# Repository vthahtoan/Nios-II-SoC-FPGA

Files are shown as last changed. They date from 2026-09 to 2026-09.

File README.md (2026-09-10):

# Direct Digital Synthesizer (DDS) System on Nios II SoC

## Overview
This project presents a hardware-software co-design of a Direct Digital Synthesizer (DDS) implemented on an Altera Cyclone II FPGA (EP2C35F672C6). The system generates continuous analog waveforms, including Square, Triangle, Sine, and Cosine, by leveraging a custom digital logic circuit integrated with a Nios II embedded processor. 

## Key Features
*   **Flexible IP Core Design:** The Custom IP supports two methods for Phase-to-Amplitude conversion:
    *   **LUT (Look-Up Table):** Utilizes Block RAM for fast, 1-2 clock cycle latency.
    *   **CORDIC Algorithm:** An 8-stage pipeline architecture that computes trigonometric functions using only adders and shifters, consuming 0 bits of RAM.
*   **Avalon-MM Interface:** Seamless communication between the Nios II master and the custom DDS IP slave through the Avalon Switch Fabric.
*   **High Performance:** Achieved a maximum operating frequency (Fmax) of 208.68 MHz (CORDIC) and 195.85 MHz (LUT).
*   **Bare-metal C Software:** The Nios II processor dynamically controls the output frequency (phase increment) and wave type via low-level register manipulation.

## Repository Structure
<!-- HUONG DAN: Ban co the sua ten cac thu muc duoi day cho khop voi cay thu muc thuc te -->
    ├── doc/                 # Presentation slides, block diagrams, and waveform images
    ├── rtl/                 # Verilog HDL source files and Qsys system design
    ├── tb/                  # Testbench files for ModelSim verification
    ├── sw/                  # Embedded C code (Eclipse SBT) and BSP settings
    └── README.md

## System Architecture
The SoC architecture consists of a Nios II Processor, On-chip Memory, JTAG UART, and the custom wave_gen_avalon IP, all interconnected via the Avalon bus.

## Implementation Results & Comparison
The design was highly optimized for both logic utilization and speed. Compared to reference papers, this implementation achieves superior performance:

| Parameter | LUT Design | CORDIC Design |
| :--- | :--- | :--- |
| **Max Frequency (Fmax)** | 195.85 MHz | 208.68 MHz |
| **Block RAM usage** | ~ 0.111 BRAM | ~ 0.003 BRAM |
| **Total Equivalent Area** | 1582.5 | 2275.496 |

## Verification
The system functionality was strictly verified using:
1.  **ModelSim:** RTL waveform simulation for all wave types.
2.  **SignalTap II Logic Analyzer:** Real-time on-chip debugging to capture physical signals on the DE2 board.

## Author
*   **Võ Thanh Toàn** - *Computer Engineering, UIT*

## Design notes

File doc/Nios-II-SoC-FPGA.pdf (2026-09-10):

KHOA KỸ THUẬT MÁY TÍNH

## Nội dung trình bày:

11 May 2026 | 1

### 1. Tổng quan hệ thống phát sóng số (DDS)

### 2. Thiết kế lõi IP phần cứng

### 3. Kiến trúc SoC & Giao tiếp Avalon-MM

### 4. Tích hợp phần mềm trên Nios II

### 5. So sánh với các bài báo

### 6. Mô phỏng và Nạp KIT DE2

Copyrights 2026 UIT. All Rights Reserved.

### 1. Tổng quan về hệ thống phát sóng số (DDS)

2

DDS (Direct Digital Synthesizer): Là kỹ thuật tạo ra các dạng sóng tương tự (Sin, Cos, Tam giác, Vuông) từ một hệ thống mạch kỹ thuật số.

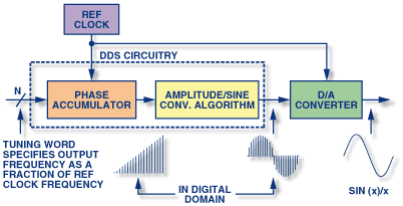
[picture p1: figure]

11 May 2026 | Copyrights 2026 UIT. All Rights Reserved.

### 1. Tổng quan về hệ thống phát sóng số (DDS)

3

Bộ cộng dồn pha (Phase Accumulator):

- Chức năng: Tích lũy giá trị bước nhảy pha sau mỗi chu kỳ clock.
- Quyết định: Tần số của tín hiệu ngõ ra.
11 May 2026 | Copyrights 2026 UIT. All Rights Reserved.

Bộ chuyển đổi Pha sang Biên độ (Phase-to-Amplitude Converter):

- Chức năng: Ánh xạ giá trị pha từ bộ cộng dồn thành biên độ sóng tương ứng.
- Phương pháp thực hiện: Bảng tra bộ nhớ (LUT) hoặc Thuật toán CORDIC.

### 1. Tổng quan về hệ thống phát sóng số (DDS)

4

Công thức tính tần số từ bước nhảy pha:

11 May 2026 | Copyrights 2026 UIT. All Rights Reserved.
- fout: Tần số của tín hiệu sóng ngõ ra mà hệ thống cần tổng hợp.
- M: Bước nhảy pha (Phase Increment)
- fclk: Tần số xung nhịp hoạt động của toàn hệ thống.
- 2

N: Độ phân giải pha tối đa, đại diện cho tổng số điểm pha rời rạc trong một chu kỳ sóng hoàn chỉnh.

### 2. Thiết kế lõi IP phần cứng

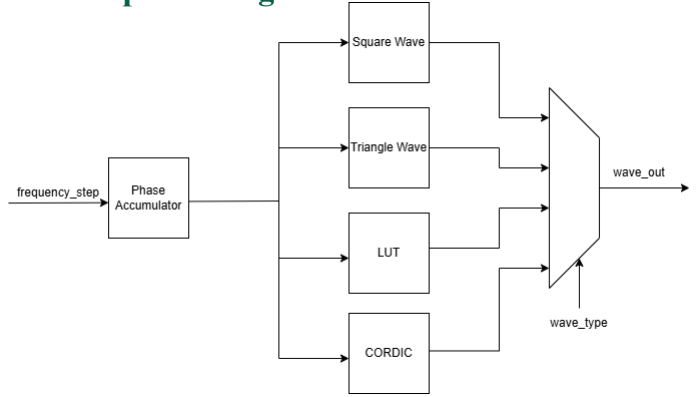
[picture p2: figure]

11 May 2026 | Copyrights 2026 UIT. All Rights Reserved. | 5

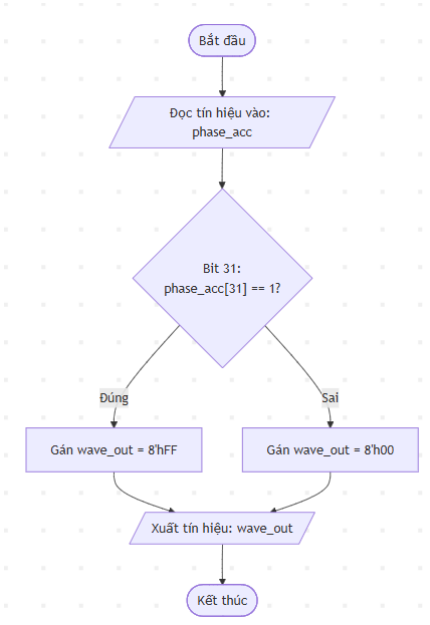
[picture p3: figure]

### 2. Thiết kế lõi IP phần cứng

### 2.1. IP tạo sóng vuông

Nguyên lý hoạt động:
- Lấy giá trị bit cao bộ cộng pha.
- Thực hiện gán giá trị cho ngõ ra phụ thuộc vào giá trị bit cao ngõ vào.

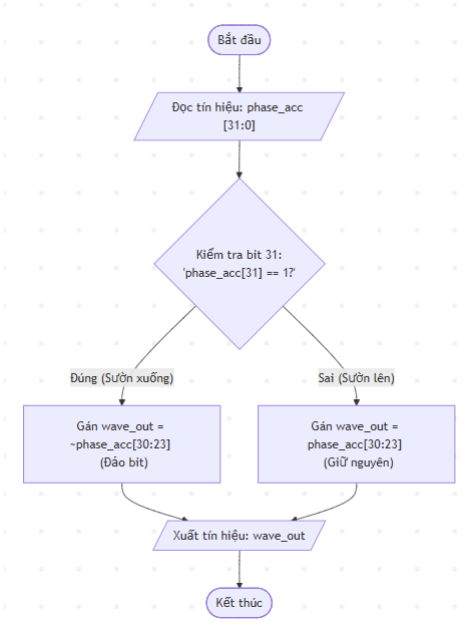
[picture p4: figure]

### 2. Thiết kế lõi IP phần cứng

### 2.2. IP tạo sóng tam giác

Nguyên lý hoạt động:
- Lấy giá trị bit cao bộ cộng pha.
- Gán giá trị ngõ ra bằng hoặc đảo của 8 bit cao của bộ cộng pha.

### 2. Thiết kế lõi IP phần cứng

### 2.3. IP tạo sóng Sin/Cosin bằng phương pháp Bảng tra (LUT)

Nguyên lý thiết kế:
- Sử dụng tài nguyên bộ nhớ nội của FPGA (Block RAM) để cấu hình một bảng ROM lưu trữ 256 giá trị biên độ mẫu của một chu kỳ sóng Sin.
- Dữ liệu biên độ (8-bit) được nạp sẵn từ tệp tin sine.txt trong quá trình khởi tạo hệ thống.

### 2. Thiết kế lõi IP phần cứng

### 2.3. IP tạo sóng Sin/Cosin bằng phương pháp Bảng tra (LUT)

Cơ chế thực thi thuật toán:
- Ánh xạ địa chỉ: Trích xuất 8-bit trọng số cao nhất của bộ cộng dồn pha (phase_acc[31:24]) làm chỉ số địa chỉ để truy vấn bảng ROM.
- Tạo sóng Sin: Giá trị biên độ được đọc trực tiếp từ ROM tại địa chỉ tương ứng: sin_out <= sin_rom[index].
- Tạo sóng Cosin: Tận dụng tính chất lệch pha 90 độ trong lượng giác. Với bảng 256 mẫu, khoảng lệch này tương ứng với 64 đơn vị địa chỉ: cos_out <= sin_rom[index + 64].

### 2. Thiết kế lõi IP phần cứng

### 2.3. IP tạo sóng Sin/Cosin bằng phương pháp Bảng tra (LUT)

Đánh giá kỹ thuật:
- Tốc độ: Thời gian đáp ứng cực nhanh, dữ liệu xuất hiện ngay sau khi có địa chỉ (độ trễ truy cập RAM thấp).
- Tài nguyên: Tiêu tốn tài nguyên Block RAM tỉ lệ thuận với độ phân giải và số lượng mẫu lưu trữ. Đây là cơ sở để so sánh hiệu quả với thuật toán CORDIC ở phần tiếp theo.

### 2. Thiết kế lõi IP phần cứng

### 2.4. IP tạo sóng Sin/Cosin bằng thuật toán CORDIC

Nguyên lý thiết kế:
- Sử dụng thuật toán xoay vector liên tiếp

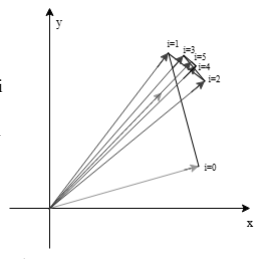
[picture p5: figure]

để tính toán giá trị Sin và Cos trực tiếp tại thời gian thực.
- Tối ưu hóa mức cổng logic: Loại bỏ hoàn toàn các bộ nhân, thay thế bằng các phép dịch bit và cộng/trừ.

### 2. Thiết kế lõi IP phần cứng

### 2.4. Lõi IP tạo sóng Sin/Cosin bằng thuật toán CORDIC

Nguyên lý thiết kế:
- Xử lý góc phần tư: Sử dụng 2-bit cao nhất của bộ cộng pha (phase_acc[31:30]) để đưa góc về phạm vi 0 - 90 độ trước khi tính toán.
- Kiến trúc Pipeline 8 tầng: Thuật toán được chia thành 8 giai đoạn xử lý nối tiếp. Tại mỗi tầng, vector được xoay một góc arctan(2⁻i
).
- Hiệu chỉnh ngõ ra: Khôi phục dấu dựa trên góc phần tư ban đầu và thực hiện dịch trục biên độ (+128) để tạo tín hiệu không dấu 8-bit tương thích với hệ thống.

### 2. Thiết kế lõi IP phần cứng

### 2.4. Lõi IP tạo sóng Sin/Cosin bằng thuật toán CORDIC

Đánh giá kỹ thuật:
- Tài nguyên: Hoàn toàn không sử dụng bộ nhớ RAM, giúp tiết kiệm tài nguyên Block RAM cho các thành phần khác của SoC.
- Hiệu năng: Kiến trúc Pipeline cho phép hệ thống đạt tần số hoạt động (Fmax) cao và xuất ra một mẫu dữ liệu mới trên mỗi chu kỳ xung nhịp.

### 2. Thiết kế lõi IP phần cứng

### 2.5. Tính linh hoạt trong thiết kế IP Core

Thiết kế tích hợp tham số tùy biến USE_CORDIC cho phép tối ưu hóa tài nguyên dựa trên đặc thù chip FPGA: lựa chọn LUT để đạt tốc độ phản hồi cực nhanh (tốn RAM) hoặc thuật toán CORDIC để tiết kiệm tuyệt đối bộ nhớ bằng tài nguyên logic. Sự linh hoạt này giúp lõi IP dễ dàng thích ứng với mọi kịch bản triển khai.

### 2. Thiết kế lõi IP phần cứng

### 2.5. Tính linh hoạt trong thiết kế IP Core

Tiêu chí | Bảng tra (LUT) | Thuật toán CORDIC
Tài nguyên RAM | Tốn Block RAM (tỉ lệ với mẫu) | Không sử dụng RAM (0 bit)
Tài nguyên Logic | Rất thấp | Trung bình (Adder/Shifter)
Latency | 1 - 2 Clock cycles | 8 Clock cycles (Pipeline)
Độ chính xác | Phụ thuộc mật độ bảng tra | Rất cao (độ phân giải bit)

### 3. Kiến trúc SoC & Giao tiếp Avalon-MM

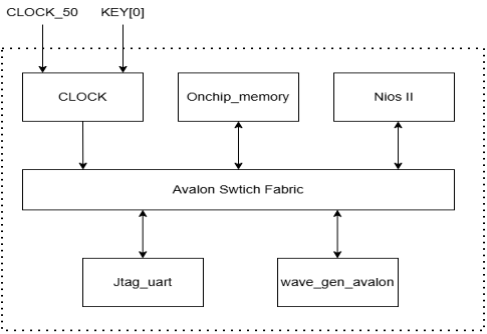
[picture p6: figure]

### 3. Kiến trúc SoC & Giao tiếp Avalon-MM

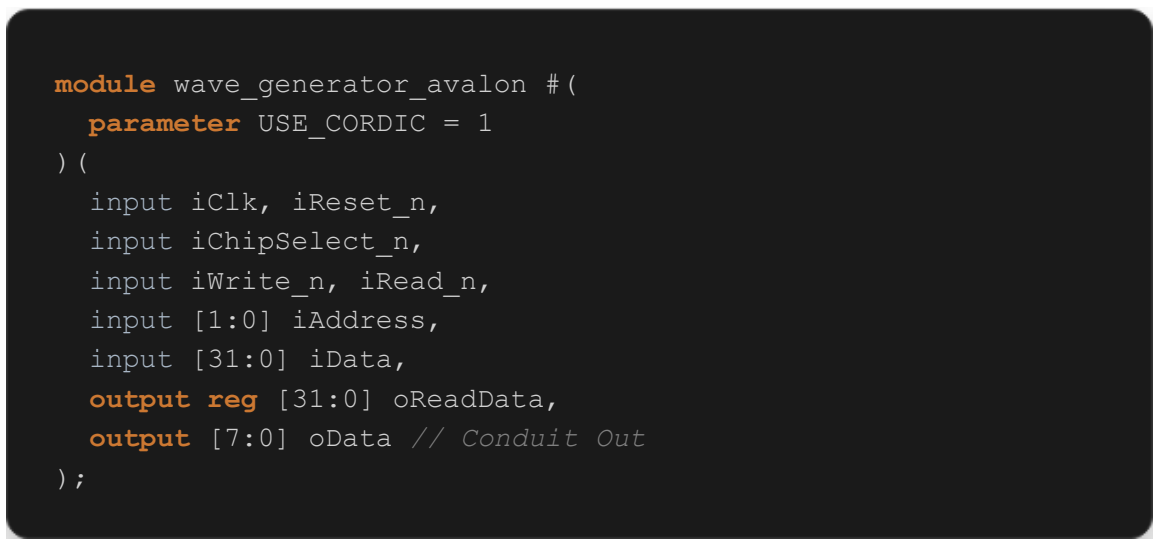
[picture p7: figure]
module wave_generator_avalon #(; parameter USE_CORDIC = 1; input iClk, iReset_n,; input iChipSelect_n,; input iWrite_n, iRead_n,; input [1:0] iAddress,; input [31:0] iData,; output reg [31:0] oReadData,; output [7:0] oData // Conduit Out

iClk, iReset_n

Cấp xung nhịp (50MHz) và tín hiệu khởi tạo hệ thống đồng bộ.

Select, Write, Read, Address

Điều phối việc truy cập và giải mã địa chỉ thanh ghi từ Nios II.

oData [7:0] (Conduit)

Tín hiệu sóng ngõ ra xuất trực tiếp tới chân GPIO vật lý.

iData / oReadData [31:0]

Bus dữ liệu 2 chiều: Nhận lệnh cấu hình (Write) và phản hồi

trạng thái (Read).

### 3. Kiến trúc SoC & Giao tiếp Avalon-MM

Khai báo thanh ghi nội

Sử dụng reg 32-bit và 2-bit để lưu giữ cấu hình từ CPU, làm trung

gian cung cấp dữ liệu cho lõi xử lý sóng.

Ánh xạ Địa chỉ
Sử dụng iAddress làm tín hiệu chọn luồng. Dữ liệu từ bus iData

sẽ được chốt vào đúng thanh ghi khi Master cấp lệnh Ghi.

Trạng thái Khởi tạo (Reset)
Khi có tín hiệu iReset_n, hệ thống tự động thiết lập tần số mặc

định và dạng sóng cơ bản để đảm bảo ổn định.

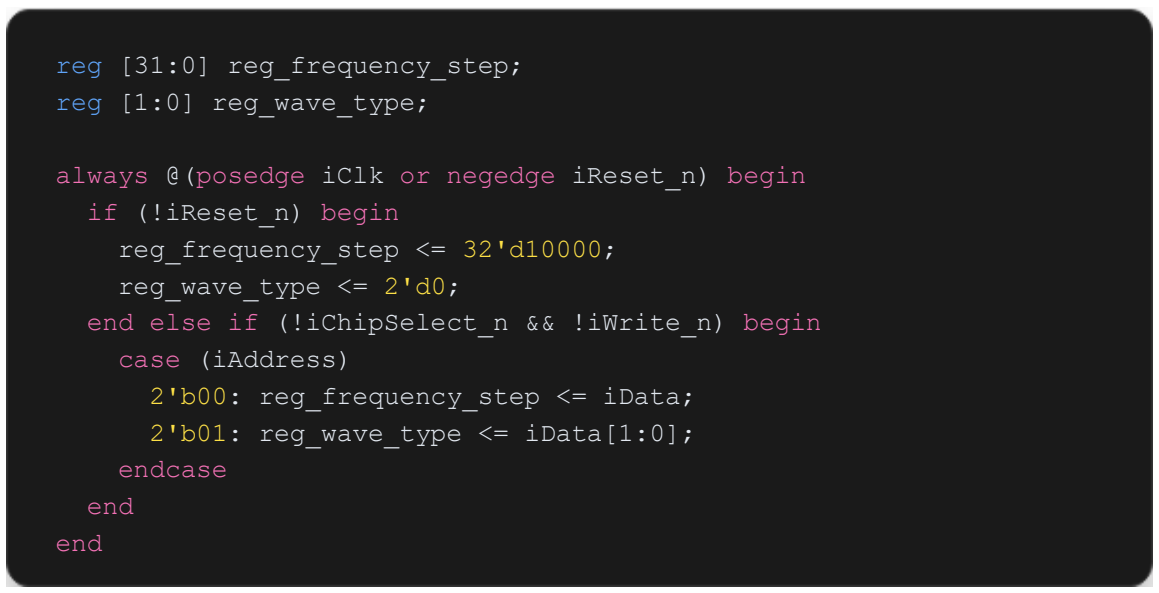
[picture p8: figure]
reg [31:0] reg_frequency_step;; reg [1:0] reg_wave_type;; if (!iReset_n) begin; reg_frequency_step <= 32'd10000;; reg_wave_type <= 2'd0;; case (iAddress); 2'b00: reg_frequency_step <= iData;; 2'b01: reg_wave_type <= iData[1:0];; endcase; end

always @(posedge iClk or negedge iReset_n) begin

end else if (!iChipSelect_n && !iWrite_n) begin

### 3. Kiến trúc SoC & Giao tiếp Avalon-MM

Mạch Tổ hợp

Khác với logic Ghi, logic Đọc được thiết kế dạng Mạch tổ hợp

giúp tối ưu hóa tốc độ truy xuất.

Trạng thái An toàn
Khi không có lệnh Đọc, ngõ ra oReadData luôn được gán bằng
0. Điều này giúp tránh xung đột dữ liệu trên Bus Avalon và tiết

kiệm năng lượng.

Gộp Bit

Vì Bus dữ liệu rộng 32-bit, thanh ghi reg_wave_type (2-bit)

được gộp thêm 30 bit '0' để đảm bảo tính toàn vẹn dữ liệu khi

truyền về CPU.

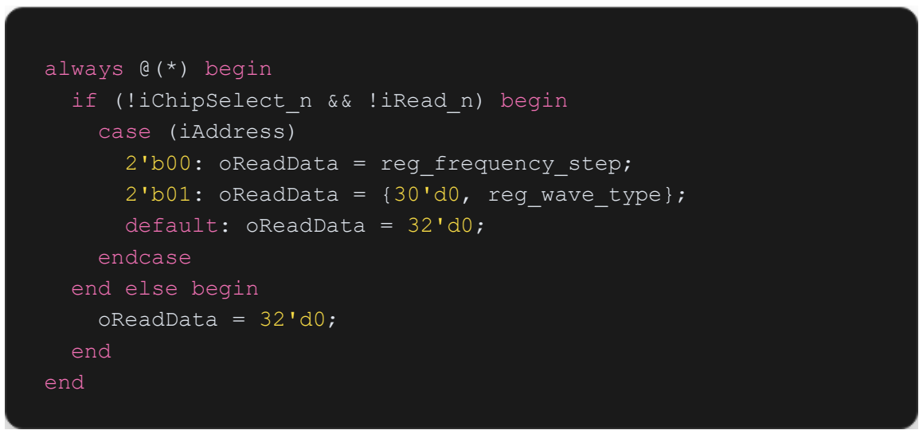
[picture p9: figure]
always @(*) begin; if (!iChipSelect_n && !iRead_n) begin; case (iAddress); 2'b00: oReadData = reg_frequency_step;; default: oReadData = 32'd0;; endcase; end else begin; oReadData = 32'd0;; end

2'b01: oReadData = {30'd0, reg_wave_type};

### 3. Kiến trúc SoC & Giao tiếp Avalon-MM

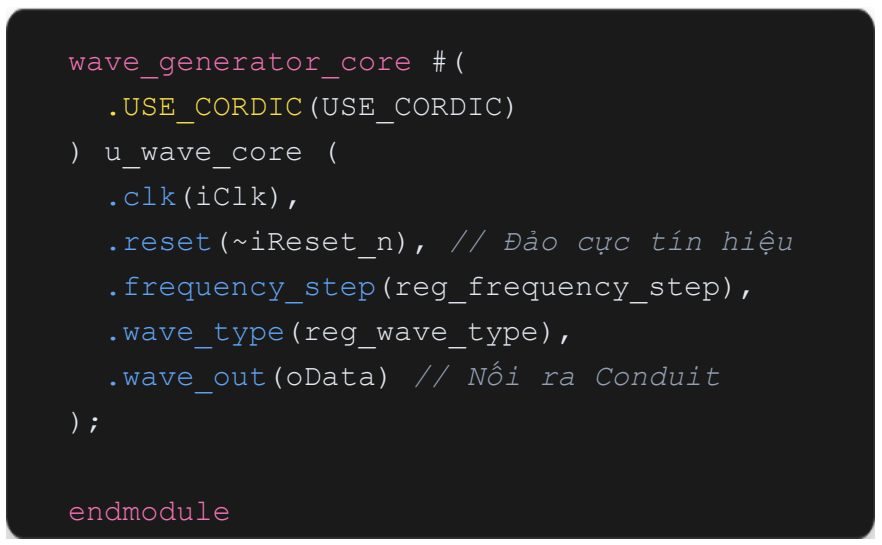
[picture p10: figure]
wave_generator_core #(; .USE_CORDIC(USE_CORDIC); ) u_wave_core (; .clk(iClk),; .reset(~iReset_n), // Đảo cực tín hiệu; .frequency_step(reg_frequency_step),; .wave_type(reg_wave_type),; .wave_out(oData) // Nối ra Conduit; endmodule

Truyền Tham số
Tham số USE_CORDIC từ lớp vỏ Avalon được truyền thẳng xuống

lõi Core bên dưới, cho phép người dùng tinh chỉnh kiến trúc trực tiếp

từ giao diện Qsys.

Bơm dữ liệu & Xuất tín hiệu
Các thanh ghi nội được nối trực tiếp vào ngõ vào của Lõi. Đồng thời,

ngõ ra wave_out được nối xuyên thấu ra oData để thoát khỏi hệ

thống Bus.

### 3. Kiến trúc SoC & Giao tiếp Avalon-MM

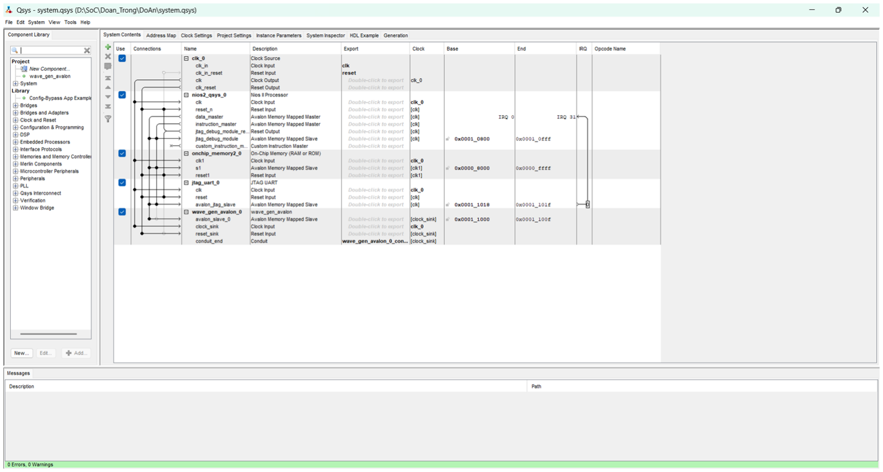
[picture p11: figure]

Tích hợp lõi IP DDS
vào kiến trúc SoC trên
công cụ Qsys.

### 3. Kiến trúc SoC & Giao tiếp Avalon-MM

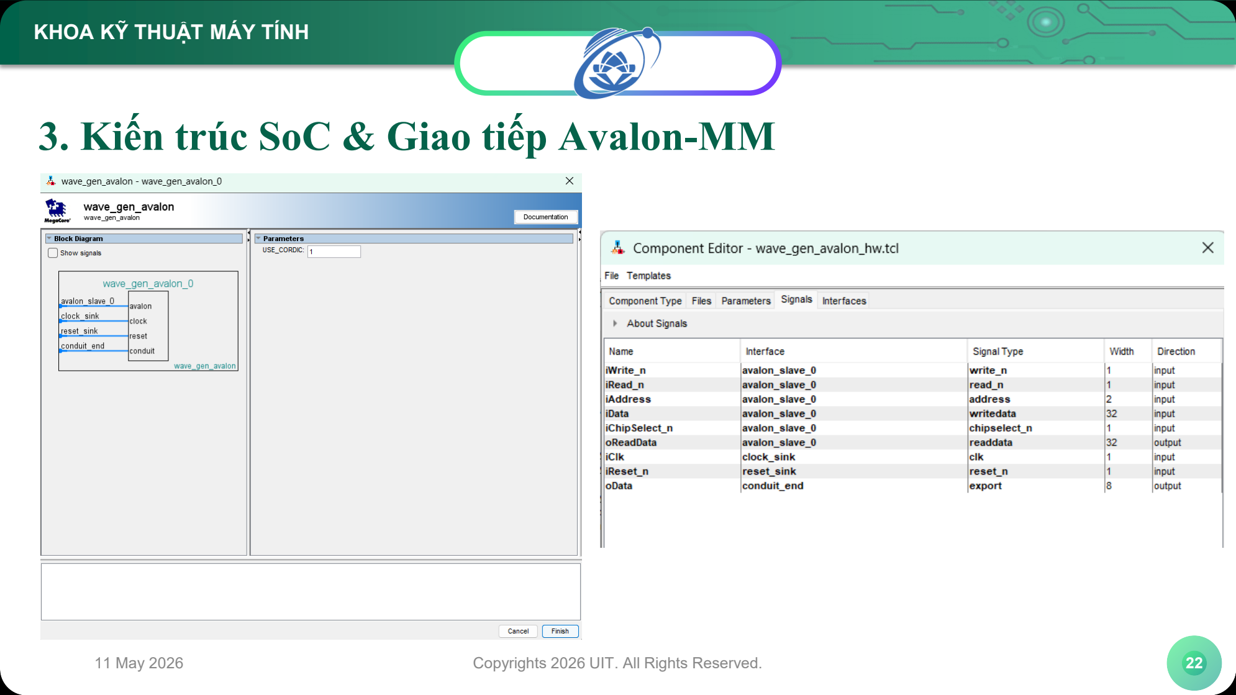
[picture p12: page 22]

### 4. Tích hợp phần mềm trên Nios II

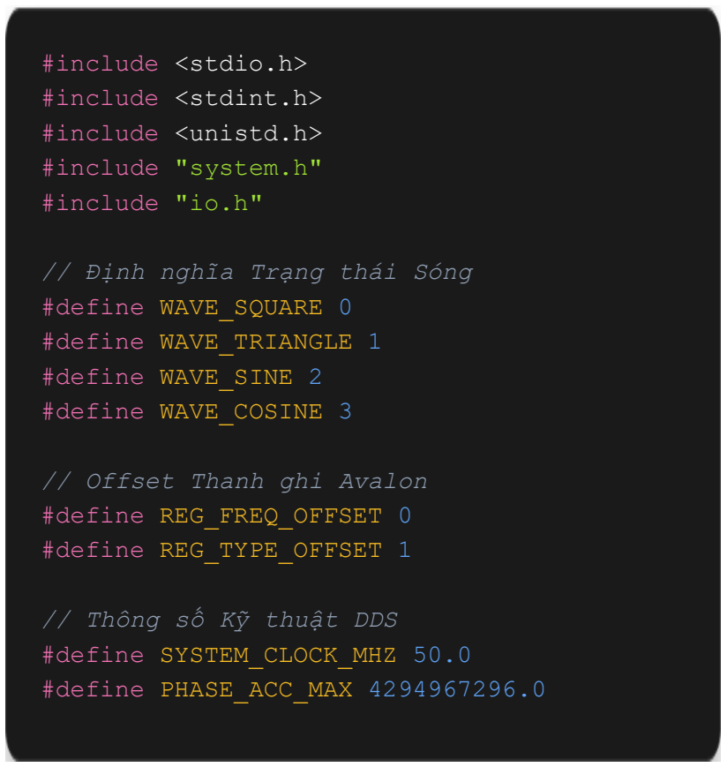
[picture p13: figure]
#include <stdio.h>; #include <stdint.h>; #include <unistd.h>; #include "system.h"; #include "io.h"; // Định nghĩa Trạng thái Sóng; #define WAVE_SQUARE 0; #define WAVE_TRIANGLE 1; #define WAVE_SINE 2; #define WAVE_COSINE 3; // Offset Thanh ghi Avalon; #define REG_FREQ_OFFSET 0; #define REG_TYPE_OFFSET 1; // Thông số Kỹ thuật DDS; #define SYSTEM_CLOCK_MHZ 50.0; #define PHASE_ACC_MAX 4294967296.0

Thư viện HAL
system.h cung cấp các macro địa chỉ vật lý (Base Address) được

sinh ra tự động từ Qsys. io.h cung cấp các lệnh đọc/ghi cấp thấp để

tương tác với Avalon Bus.

Ánh xạ Thanh ghi
Các hằng số OFFSET 0 và OFFSET 1 tương ứng chính xác với

địa chỉ 2'b00 và 2'b01 đã thiết kế trong khối phần cứng Avalon

Wrapper.

Hằng số Tính toán DDS
Sử dụng 50.0 MHz làm xung nhịp hệ thống. Đặc biệt, hằng số

4294967296.0 chính là 2³²

- đại diện cho độ phân giải tối đa của

Bộ cộng dồn pha (Phase Accumulator) 32-bit.

### 4. Tích hợp phần mềm trên Nios II

Hàm Cấu hình Tần số

Vi xử lý tính toán bước nhảy pha (step) theo công thức DDS. Phép tính

sử dụng kiểu double để triệt tiêu sai số làm tròn khi chia cho tần số hệ

thống, sau đó mới ép về kiểu uint32_t để nạp vào thanh ghi.

Ghi dữ liệu xuống IP Core

Sử dụng lệnh IOWR để truyền dữ liệu qua Avalon-MM. Địa chỉ ghi

được xác định bằng Base Address của khối IP kết hợp với OFFSET 0

(Thanh ghi tần số) hoặc OFFSET 1 (Thanh ghi chọn dạng sóng).

Bảo vệ phần cứng
Phép toán AND 0x03 bảo vệ IP Core khỏi các giá trị lựa chọn sóng không hợp lệ.

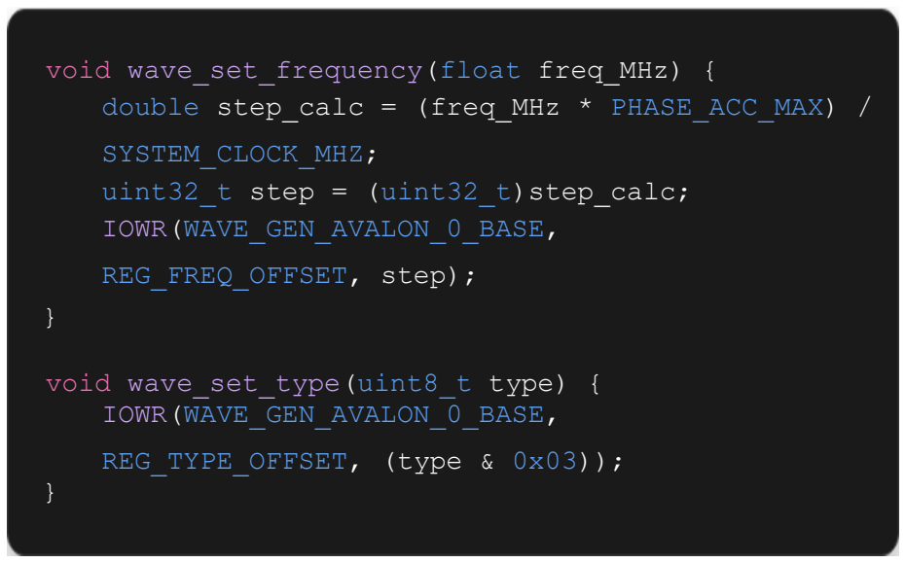
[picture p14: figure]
SYSTEM_CLOCK_MHZ;; uint32_t step = (uint32_t)step_calc;; IOWR(WAVE_GEN_AVALON_0_BASE,; REG_FREQ_OFFSET, step);; void wave_set_type(uint8_t type) { IOWR(WAVE_GEN_AVALON_0_BASE,; REG_TYPE_OFFSET, (type & 0x03));

void wave_set_frequency(float freq_MHz) {
double step_calc = (freq_MHz * PHASE_ACC_MAX) /

### 4. Tích hợp phần mềm trên Nios II

Khởi tạo hệ thống
Ngay sau khi khởi động, chương trình thiết lập tần số hoạt động

mặc định là 500 KHz. Lệnh này gửi thông số bước nhảy pha trực

tiếp xuống thanh ghi phần cứng.

Vòng lặp vô tận

Sử dụng cấu trúc while(1) để đảm bảo hệ thống duy trì việc phát

tín hiệu liên tục, phục vụ quá trình đo đạc và quan sát dạng sóng

trong thời gian dài.

Chuyển đổi dạng sóng tuần tự
Hệ thống tự động luân chuyển giữa các dạng sóng (Vuông, Tam giác, Sin, Cos). Mỗi trạng thái được duy trì trong 2 giây nhờ hàm usleep, cho phép bộ SignalTap II bắt mẫu tín hiệu ổn định.

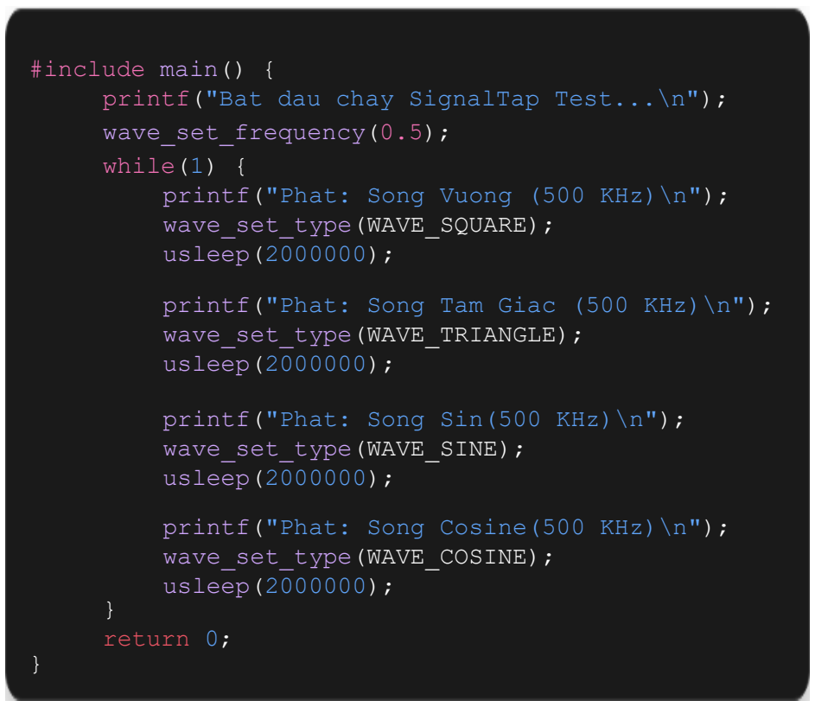
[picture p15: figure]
#include main() {; wave_set_frequency(0.5);; while(1) { printf("Phat: Song Vuong (500 KHz)\n");; wave_set_type(WAVE_SQUARE); usleep(2000000);; wave_set_type(WAVE_TRIANGLE); usleep(2000000);; printf("Phat: Song Sin(500 KHz)\n");; wave_set_type(WAVE_SINE); usleep(2000000);; printf("Phat: Song Cosine(500 KHz)\n");; wave_set_type(WAVE_COSINE); usleep(2000000);; } return 0;

printf("Bat dau chay SignalTap Test...\n");

printf("Phat: Song Tam Giac (500 KHz)\n");

### 5. So sánh với các bài báo

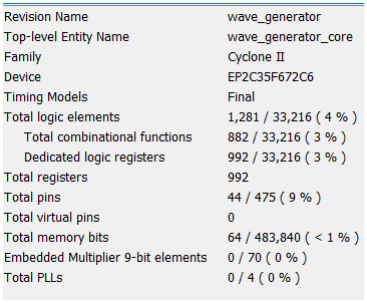
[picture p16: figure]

### 5.1. Báo cáo tài nguyên

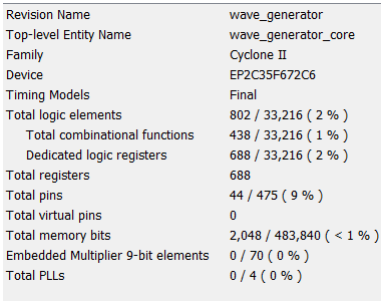
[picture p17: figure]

CORDIC | LUT

### 5. So sánh với các bài báo

### 5.1. Báo cáo tài nguyên

Quy đổi Bram LUT:

- 2048 / 18432 ≈ 0.111 Bram
- LUT: 0.111 x 800 ≈ 89
- FF: 0.111 x 32 = 3.5
Tổng tài nguyên:

802 (LUT) + 688 (FF) + 89 + 3.5 = 1582.5

### 5. So sánh với các bài báo

### 5.1. Báo cáo tài nguyên

Quy đổi Bram CORDIC:

- 64 / 18432 ≈ 0.003 Bram
- LUT: 0.003 x 800 = 2.4
- FF: 0.003 x 32 = 0.096
Tổng tài nguyên:

1281 (LUT) + 992 (FF) + 2.4 + 0.096 = 2275.496

### 5. So sánh với các bài báo

### 5.2. Tần số tối đa

CORDIC | LUT
208.68MHz | 195.85MHz

### 5. So sánh với các bài báo

### 5.2. So sánh

Bài báo 1: Pipelined CORDIC Design on FPGA for a Digital Sine and

Cosine Waves Generator - Esteban O. Garcia, Rene Cumplido, Miguel Arias

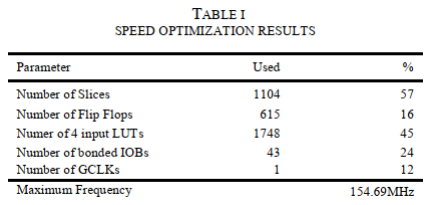
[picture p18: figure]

### 5. So sánh với các bài báo

### 5.2. So sánh

Tổng tài nguyên tối ưu tốc độ:

615 (FF) + 1748 (LUT) = 2363 Tổng tài nguyên tối ưu diện tích:

570 (FF) + 1737 (LUT) = 2307 => Kết luận: Thiết kế của nhóm tối ưu hơn thiết kế trong bài báo cả về mặt

diện tích (2275 < 2307) lẫn tốc độ (208.68MHz > 154.69MHz)

### 5. So sánh với các bài báo

### 5.2. So sánh

Bài báo 2: High-precision design of DDS Based on FPGA - Xiaochu Wang,

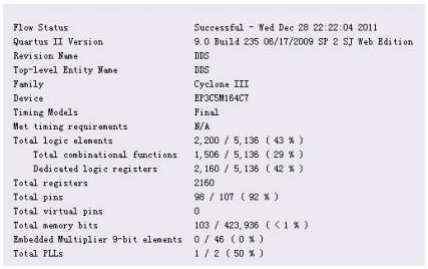
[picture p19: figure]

Qiujun Mei

### 5. So sánh với các bài báo

### 5.2. So sánh

Quy đổi Bram:

- 103 / 18432 ≈ 0.005 Bram
- LUT: 0.005 x 800 = 4
- FF: 0.005 x 32 = 0.16
Tổng tài nguyên:

2200 (LUT) + 2160 (FF) + 4 + 0.16 = 4364.16 => Kết luận: Thiết kế của nhóm tối ưu hơn về phần tài nguyên rất nhiều. Và thiết

kế của nhóm cũng chạy tốt ở mức 100MHz được thiết lập trong bài báo

### 6. Mô phỏng và Nạp KIT DE2

### 6.1. Mô phỏng ModelSim

- Kết quả mô phỏng ModelSim cho thấy mạch thực hiện tạo sóng như mong đợi.
- Frequency step được cấu
hình ở giá trị 85899345
tương đương với tần số sóng 1MHz.

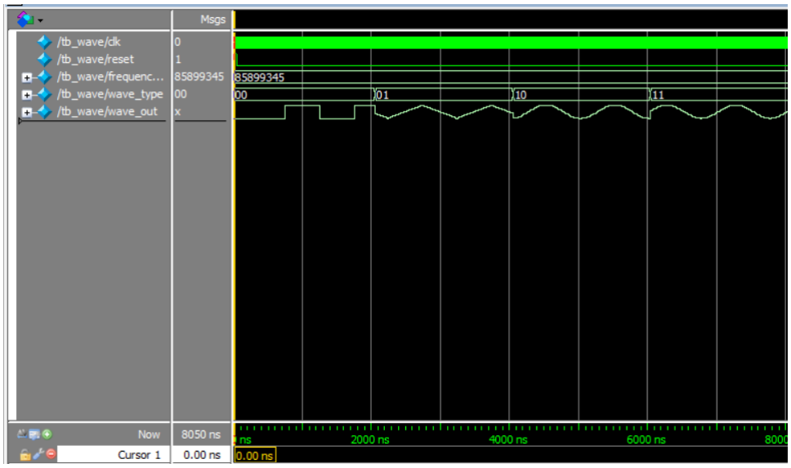
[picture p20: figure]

### 6. Mô phỏng và Nạp KIT DE2

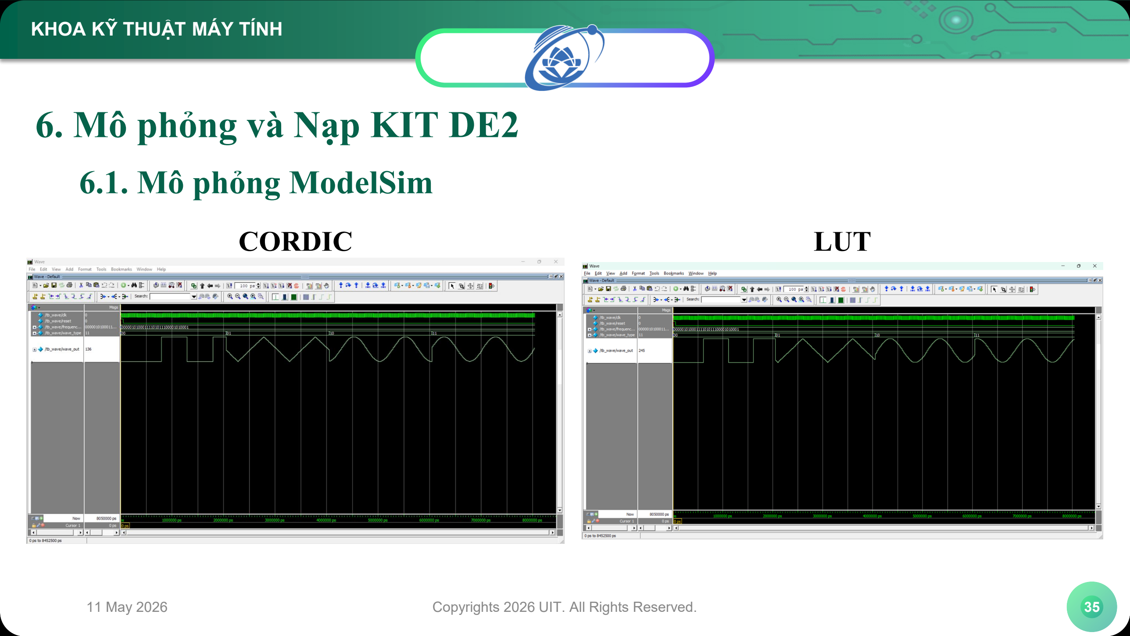
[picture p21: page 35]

### 6.1. Mô phỏng ModelSim

CORDIC | LUT

### 6. Mô phỏng và Nạp KIT DE2

### 6.2. Nạp KIT DE2

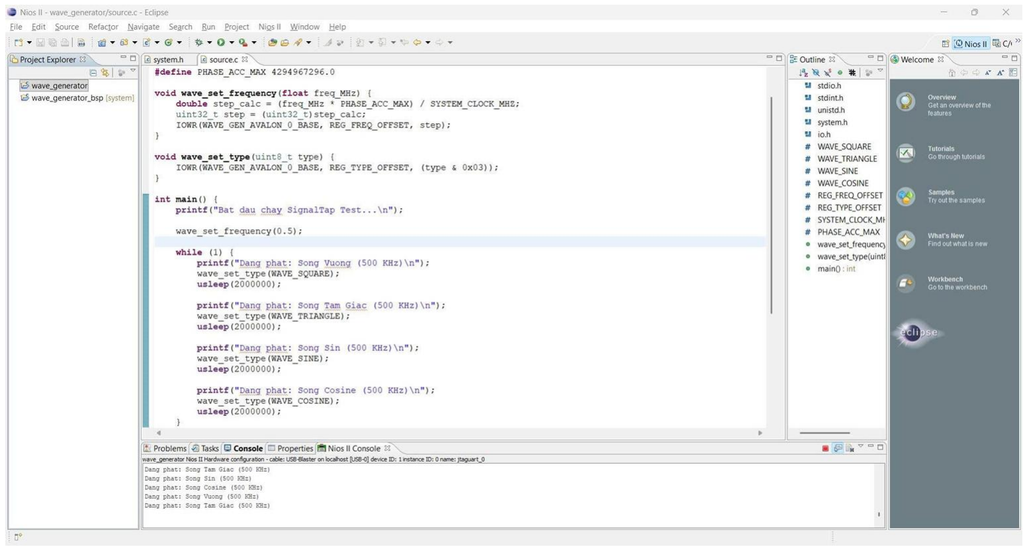
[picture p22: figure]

Triển khai mã C lên
phần cứng

### 6. Mô phỏng và Nạp KIT DE2

### 6.2. Nạp KIT DE2

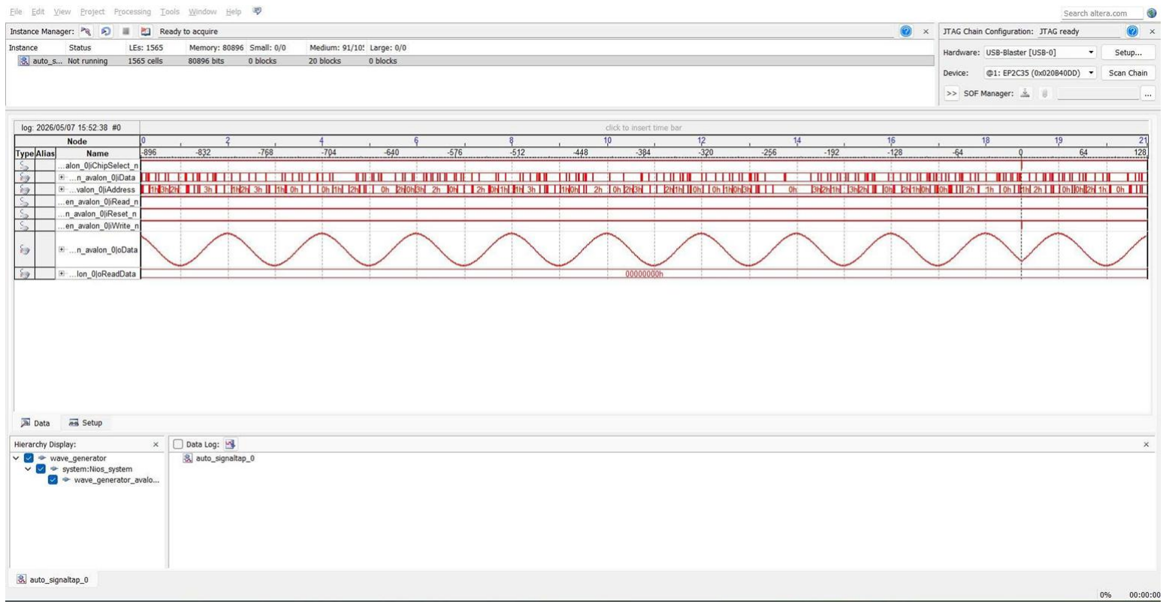
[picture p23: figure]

Kiểm chứng dạng
sóng thực tế trên chip
bằng SignalTap II
Logic Analyzer (Độ
sâu: 1000 samples).

### 6. Mô phỏng và Nạp KIT DE2

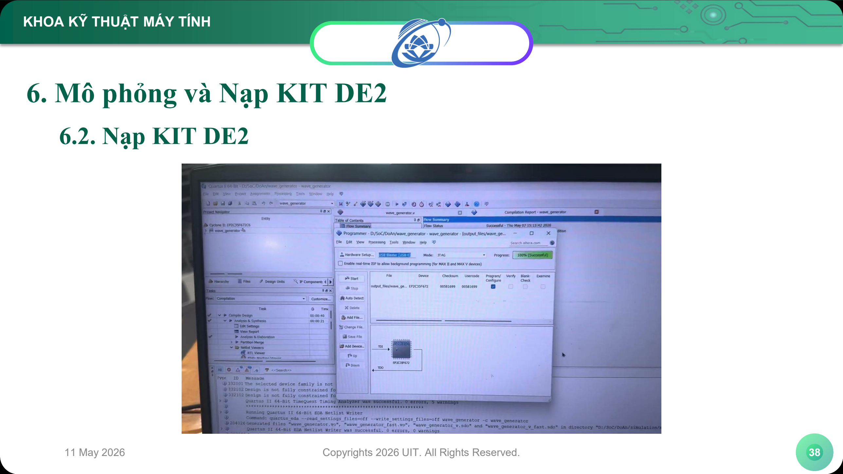
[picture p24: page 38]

### 6.2. Nạp KIT DE2

DoAn.MOV (http://drive.google.com/file/d/1quY3RNdwPAC2ZG4skANsRvMsipnUS0OB/view)

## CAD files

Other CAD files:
rtl/stp1.stp

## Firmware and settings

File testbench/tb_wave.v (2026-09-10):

`timescale 1ns / 1ps

module tb_wave;

    reg clk;
    reg reset;
    reg [1:0] address;
    reg write;
    reg [31:0] writedata;
    wire [7:0] wave_out;

	wave_generator_avalon #(
        .USE_CORDIC(1)
    ) dut (
        .iClk(clk),
        .iReset_n(~reset),
        .iChipSelect_n(1'b0),
        .iWrite_n(~write),
        .iRead_n(1'b1),
        .iAddress(address),
        .iData(writedata),
        .oReadData(),
        .oData(wave_out)
    );

    always #10 clk = ~clk;

    initial begin
        clk = 0;
        reset = 1;
        address = 0;
        write = 0;
        writedata = 0;

        #100 reset = 0;
        #100;

        address = 2'b00;
        writedata = 32'd10000000; 
        write = 1;
        #20 write = 0;
        #100;

        address = 2'b01;
        writedata = 32'd0;
        write = 1;
        #20 write = 0;
        #50000;

        address = 2'b01;
        writedata = 32'd1;
        write = 1;
        #20 write = 0;
        #50000;

        address = 2'b01;
        writedata = 32'd2;
        write = 1;
        #20 write = 0;
        #50000;

        address = 2'b01;
        writedata = 32'd3;
        write = 1;
        #20 write = 0;
        #50000;

        $display("Mo phong ket thuc thanh cong!");
        $stop;
    end

endmodule
